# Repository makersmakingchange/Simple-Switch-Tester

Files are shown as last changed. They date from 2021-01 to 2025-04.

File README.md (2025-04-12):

# Simple Switch Tester
The Simple Switch Tester is a cost effective, open source assistive technology for testing assistive switches. When an assistive switch is connected to the tester via the 3.5 mm jack and activated, a light on the tester will illuminate indicating that the switch is functioning correctly. The tester is powered by two AAA batteries. A test button on the side of the tester allows the batteries to be tested to confirm the tester is working correctly before testing a switch.

The Simple Switch Tester is comprised of off-the-shelf electronics and 3D printed parts. The overall cost of materials is about $8 (plus $8 for component shipping).

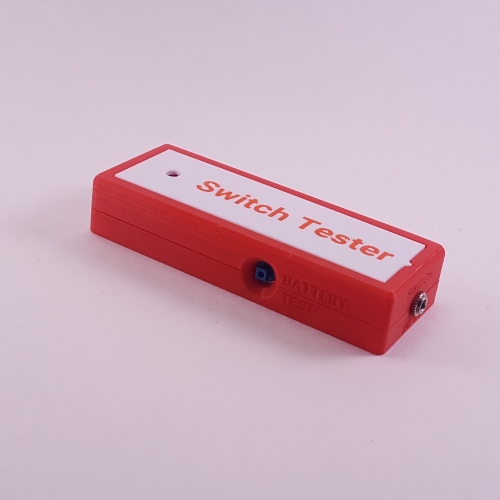
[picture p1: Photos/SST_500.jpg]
Simple Switch Tester


## More info at
 - [Makers Making Change Library Listing](https://www.makersmakingchange.com/s/product/simple-switch-tester/01tJR0000006948YAA) 

## Getting Started

### 1. Order the Off-The-Shelf Components

The [Bill of Materials](/Documentation/SST_BOM_v0.1.xlsx) lists all of the parts and components required to build the Simple Switch Tester. The electronic components may be available locally, but will probably need to be ordered online. For convenience, you can use this Digikey cart: https://www.digikey.ca/short/w37qmwmv

### 2. Print the 3D Printable components

Print the components for the switch tester case and choose an option for the case.

All of the files and individual print files can be in the [/Build_Files/3D_Printing_Files](/Build_Files/3D_Printing/) folder.

### 3. Assemble the Switch Tester

Reference the [assembly guide](/Documentation/SST_Assembly_Guide_v0.1.pdf) for the tools and steps required to build each portion. There is also a build video available at the following link: https://www.youtube.com/watch?v=CHm8Z5UD4Sw

## Files

### Documentation
| Document | Version | Link |
|---|---|---|
| Design Specifications| 0.1 | [SST_Design_Specifications](/Documentation/SST_Design_Rationale_v0.1.pdf) |
| Design Rationale | 0.1 | [SST_Design_Rationale](/Documentation/SST_Design_Rationale_v0.1.pdf) |
| Bill of Materials | 0.1 | [SST_BOM](/Documentation/SST_BOM_v0.1.xlsx) |
| Assembly Guide | 0.1 | [SST_Instructions](/Documentation/SST_Assembly_Guide_v0.1.pdf) |
| Maker Checklist | 0.1 | [SST_Checklist](/Documentation/SST_Maker_Checklist_v0.1.pdf) |
| Quick Guide | 0.1 | [SST_Quick_Guide](/Documentation/SST_Quick_Guide_v0.1.pdf) |
| Changelog | 0.1 | [SST_Changelog](/Documentation/SST_Changelog_v0.1.pdf) |

### Design Files
 - [CAD Files](/Design_Files)

### Build Files
 - [3D Printing Files](/Build_Files/3D_Printing)
 - [V0.1 3MF](/Build_Files/3D_Printing/SST_All_v0.1.3mf)

## License

Everything needed or used to design, make, test, or prepare the Simple Switch Tester is licensed under the CERN 2.0 Permissive license <https://ohwr.org/project/cernohl/wikis/Documents/CERN-OHL-version-2> (CERN-OHL-P) .

Accompanying material such as instruction manuals, videos, and other copyrightable works that are useful but not necessary to design, make, test, or prepare the Simple Switch Tester are published under a Creative Commons Attribution-ShareAlike 4.0 license <https://creativecommons.org/licenses/by-sa/4.0/> (CC BY-SA 4.0)

<!-- ABOUT MMC START -->
## About Makers Making Change
[Makers Making Change Logo](https://www.makersmakingchange.com/)

Makers Making Change is a program of [Neil Squire](https://www.neilsquire.ca/), a Canadian non-profit that uses technology, knowledge, and passion to empower people with disabilities.

Makers Making Change leverages the capacity of community based Makers, Disability Professionals and Volunteers to develop and deliver affordable Open Source Assistive Technologies.

 - Website: [www.MakersMakingChange.com](https://www.makersmakingchange.com/)
 - GitHub: [makersmakingchange](https://github.com/makersmakingchange)
 - Bluesky: [@makersmakingchange.bsky.social](https://bsky.app/profile/makersmakingchange.bsky.social)
 - Instagram: [@makersmakingchange](https://www.instagram.com/makersmakingchange)
 - Facebook: [makersmakechange](https://www.facebook.com/makersmakechange)
 - LinkedIn: [Neil Squire Society](https://www.linkedin.com/company/neil-squire-society/)
 - Thingiverse: [makersmakingchange](https://www.thingiverse.com/makersmakingchange/about)
 - Printables: [MakersMakingChange](https://www.printables.com/@MakersMakingChange)

### Contact Us
For technical questions, to get involved, or to share your experience we encourage you to [visit our website](https://www.makersmakingchange.com/) or [contact us](https://www.makersmakingchange.com/s/contact).
<!-- ABOUT MMC END -->

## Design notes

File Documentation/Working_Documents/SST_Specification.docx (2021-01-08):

# Introduction

The Simple Switch Tester is a device that provides a user with a way to assess the functionality of standard assistive switches that are equipped with a 3.5 mm plug.

# Specifications

1. Functionality
  1.1. The device must provide a 3.5 mm jack for connecting a switch.
  1.2. The device must provide feedback when a connected switch is activated.
  1.3. The device must have an enclosure to enclose and protect the electronic components.
  1.4. The device should provide a way to confirm that the tester is operational without requiring an external switch.
  1.5. The device should be able to be mounted.
2. Performance
  2.1. The device should operate
  2.2. The device should last in standby mode for no less than 6 months before requiring a battery change.
3. Environment
  3.1. The device must work in a typical indoor working environment.
4. Life expectancy
  4.1. The device should last the user up to ten years with constant use¹.
5. Maintenance
  5.1. The device battery must be easily accessible.
  5.2. The enclosure should be able to be cleaned.
  5.3. The enclosure should be able to be disinfected.
6. Target product cost
  6.1. The costs for a single device including materials and shipping must be less than $55 CAD.
  6.2. The costs for a single device including materials and shipping should be less than $20 CAD.
7. Availability of components
  7.1. The device must be comprised of components that are either commercially available off-the-shelf or that are 3D printable.
  7.2. Commercially available off-the-shelf components should available locally or online.
  7.3. 3D printable components should be printable on consumer-level fused filament fabrication (FFF) machines.
  7.4. Compatible alternative components should be listed.
8. Packaging
  8.1. The device must be easy to ship disassembled.
9. Transportation
  9.1. The device must be compact enough for ease of transportation of several devices.
  9.2. The device should be able to be transported in carry-on baggage (with lithium battery⁴.)
  9.3. The device should be able to ship in a letter-sized envelope (without battery³).
  9.4. The device should be able to ship in a half-letter sized envelope (without battery³).
10. Assembling/building
  10.1. The device should be manufacturable by a novice maker with limited tools in a remote location (e.g. at home).
  10.2. The device should be able to be assembled by a typical maker in less than an hour.
  10.3. The device should have guide pins, tracks, or other alignment markers to help guide the device assembly.
  10.4. The tools required to assemble the device should be limited to: a soldering iron, wire cutters, pliers, and/or a screwdriver.
11. Troubleshooting
  11.1. The primary user should be able to troubleshoot or reset critical product function(s) without requiring external help.
  11.2. Secondary users (caretaker, disability professional, family members, etc.) should be able to troubleshoot critical product function(s) and general functions without requiring external help.
  11.3. Troubleshooting support and documentation must be available online or in other forms for all stakeholders (primary user, secondary user, maker, etc.) and explained in non-technical terms.
12. Quantity
  12.1. The device must be able to be built in minimal quantities (i.e. 1-2).
  12.2. The device should be able to be built in larger quantities (i.e. 20-50).
13. Size and weight
  13.1. The device kit (including 3D printed casing) should not weigh more than 50g⁵.
  13.2. The device should be around the same size as a handheld device.
14. Aesthetics and finish
  14.1. The device should have a sleek look and not look bulky.
  14.2. The device should have Makers Making Change branding on the exterior.
15. Materials
  15.1. The 3D printed case must be printable in common filaments, like PLA and ABS, but not limited to other filaments.
16. Product life span
  16.1. The device should have a product lifespan of at least ten years¹.
17. Standards and specifications (provincial, national, international, etc.)
  17.1. The device must comply with Transport Canada regulation on shipping lithium metal batteries², ³.
18. Ergonomics
  18.1. The device must not have any sharp edges.
  18.2. The device should be comfortable to hold and use.
19. Quality and reliability
  19.1. The device must function reliably and consistently as a switch tester without failure.
20. Shelf life
  20.1. The device should have a shelf life of ten years¹.
21. Processes
  21.1. The enclosure design should be designed and optimized for 3D printing using a fused filament fabrication (FFF) machine.
  21.2. The enclosure design should use minimal or no support material to print.
  21.3. 3D printed components should require minimal post-processing.
22. Testing
  22.1. The device must be built and tested internally first before publication.
23. Safety
  23.1. The device must not injure the user in any way.
  23.2. The device must not pose a choking hazard.
24. Intellectual Property Protection
  24.1. The device must be released with an open-source license.
  24.2. All project deliverables should be licensed to comply with Open Source Hardware.
25. Product liability
  25.1. Any form of incorrect use of the device must not be the fault of Makers Making Change.
26. Installation and operation
  26.1. The device must have an easy to understand user manual.
  26.2. The device should have icons and arrows for instruction on the 3D printed case.
27. Disposal
  27.1. The device and its components must be able to be disposed of by regular household waste collection agencies or recycling depot, excluding the 3D printed enclosure.

# Appendix

¹ Shelf life of lithium coin battery

https://www.panasonic-batteries.com/en/specialty/lithium-coin/coin-lithium-cr2032

“Shelf Life: 10 years”

² Transport Canada on lithium batteries

https://tc.canada.ca/en/dangerous-goods/transportation-dangerous-goods/transporting-batteries

“The consignor is responsible for classifying dangerous goods (batteries in this case) in accordance with Part 2 of the TDG Regulations.”

“Yes. In Canada, the shipping and importing of lithium batteries is subject to the Transportation of Dangerous Goods Act, 1992 (TDG Act) and its regulations. They are considered dangerous goods much like gasoline, propane and sulfuric acid.”

Shipping documents are always required when transporting batteries.

Battery shipments must fully comply with the TDG Regulations

When shipping batteries by marine or air transport, consult Parts 11 and 12 of the TDG Regulations as well as the following documents:

The International Civil Aviation Organization’s Technical Instructions for the Safe Transport of Dangerous Goods by Air (ICAO Technical Instructions); or

The International Maritime Organization’s International Maritime Dangerous Goods Code (IMDG Code).

“A paper copy of the shipping document must always accompany the dangerous goods.”

“When dangerous goods are shipped by air, the shipping document must have, in the left and right margins, red hatchings that slant to the left or right.”

At minimum, the shipping document must include:

The name and address of the consignor in Canada

The shipping date

A description of the dangerous goods, in the following order:

The UN number

The shipping name of the dangerous goods

The primary and subsidiary class

Where applicable, the packing group in roman numerals

The quantity in metric (e.g., kg or L) for transports originating in Canada

Theʺ 24-Hour Numberʺ of a person who can provide technical information on the dangerous goods

The consignor’s certification

“Part 4 of the TDG Regulations requires that dangerous goods safety marks be displayed on the means of containment containing dangerous goods in transport.”

Packing Instruction 801 of Transport Canada Standard TP14850E

Batteries may be handled, offered for transport or transported in a non-UN standardized container if they are placed in a rigid container, in a wooden slatted crate or on a pallet

Batteries must be protected against short circuits

Stacked batteries must be adequately secured in tiers separated by a layer of non-conductive material

Battery terminals must not support the weight of other superimposed elements

Batteries must be packaged or secured to prevent inadvertent movement

³ UPS: How to safely pack and ship batteries

https://www.ups.com/ca/en/help-center/packaging-and-supplies/special-care-shipments/batteries.page

https://www.ups.com/assets/resources/media/en_CA/pack_ship_batteries.pdf

“Regulations require packing cells and batteries in fully enclosed inner packaging made of nonconductive material (e.g. plastic bags) and ensuring that exposed terminals or connectors are protected with non-conductive caps or tape or by other similar means.”

“Do not use envelopes or other softsided packs.”

Air Shipments of Lithium Metal Batteries of <2g of Lithium metal (Figure 9)

https://data.energizer.com/pdfs/cr2032.pdf

“Typical Weight: 3.0 grams (0.10 oz.)”

“Typical Li Content: 0.109 grams (0.0038 oz.)”

“Your package does not need to be shipped as fully regulated Dangerous Goods. Please see IATA regulations for UN3091 Section II requirements. http://www.iata.org/ All packages of 'Lithium metal batteries packed with equipment'* require the UN3091 Lithium battery mark. Also mark the package 'P.I. 969-II'.† For 'Lithium metal batteries contained in equipment', display the UN3091 Lithium battery mark for any single package that contains >4 cells or >2 batteries. Also, mark the package 'P.I. 970-II'. † Note: If there are no more than 4 cells or 2 batteries and no more than 2 packages in a consignment, no markings or labels are required.”

⁴ Canada Post shipping

https://www.canadapost.ca/cpotools/apps/far/business/farLetter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

| Canada | U.S. | International
0—30g | $1.07 / stamp $0.92 / stamp in a booklet | $1.30 | $2.71
Over 30g—50g | $1.30 | $1.94 | $3.88

TSA lithium battery carry-on rules

https://www.tsa.gov/travel/security-screening/whatcanibring/items/lithium-batteries-more-100-watt-hours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,the%20FAA%20regulations%20on%20batteries.

“Lithium batteries with more than 100 watt hours may be allowed in carry-on bags with airline approval. One spare battery, not exceeding 300 watt hours, or two spare batteries, not exceeding 160 watt hours each, are permitted in carry-on bags.”

https://www.master-instruments.com.au/products/54908/CR2032/BN.html

“0.66Wh”

© 2020 by Neil Squire. “Simple Switch Tester Specification” is licensed under the CC BY SA 4.0 License: http://creativecommons.org/licenses/by-sa/4.0 PAGE 1 OF 3 Design files available at https://www.makersmakingchange.com/project/simple-switch-tester/

V0.1 | DECEMBER 2020 Simple Switch Tester Specifications

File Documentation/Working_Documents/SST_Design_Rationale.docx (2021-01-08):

# Introduction

The Simple Switch Tester is a device used to test the functionality of an assistive switch with a 3.5 mm connection. that allowsenables a user to test the switch they have built, in order to determine if they assembled it successfully and that all the components are working. When a switch is plugged into the 3.5 mm jack and activated, an LED will light up indicating a successfully operating switch. The device can be used at build events to test a series of switches, or at home during a digital build event. The switch tester is a simple device made up of six main components: the 3.5 mm jack, a AAA battery holder, two AAA batteries, an LED, a 68 Ω resistor, and a tactile switch working in parallel that can test the batteries as well as the switch. The total cost of the device is well below other equivalent devices on the market by sourcing inexpensive components and utilizing FDM 3D printing.

Table 1: Commercially Available Options

Name | Vendor | Cost | Link
Single Switch Tester | AbleNet | $55 USD Switch Tester | https://www.ablenetinc.com/technology/single-switch-tester

Switch Selection

Currently, only one design, created by AbleNet, is available commercially as a Switch Tester.

# Ideation

## Feedback

The core purpose of the test is to provide some sort of feedback to the user if a connected with

The Simple Switch Tester incorporates an enclosure and more cost-effective components than the previous version. Below is a picture of some concepts that were explored in the ideation process. Between different enclosure shapes, components, and snap-fit and solderless methods, the newest version was created. Different circuits were considered (below sketches) when thinking of the functionality of the design, ultimately opting for a parallel circuit battery tester, as well as an external switch tester to ensure that there is no miscommunication between a dead battery versus an incorrectly assembled switch. A lithophane was chosen as the top of the enclosure because the LED can shine through, displaying whatever image and/or text is on it. In case the user can only use black or very dark filament for the lithophane, there is a version of the model with a hold for the LED to shine through. The idea of disassembling locally sourced devices and utilizing their components was explored but later decided against for reasons of consistency and availability of the components. It was discovered that the 6” wires that come with the battery holder can serve as wire for the entire circuit, eliminating the need for external wire.

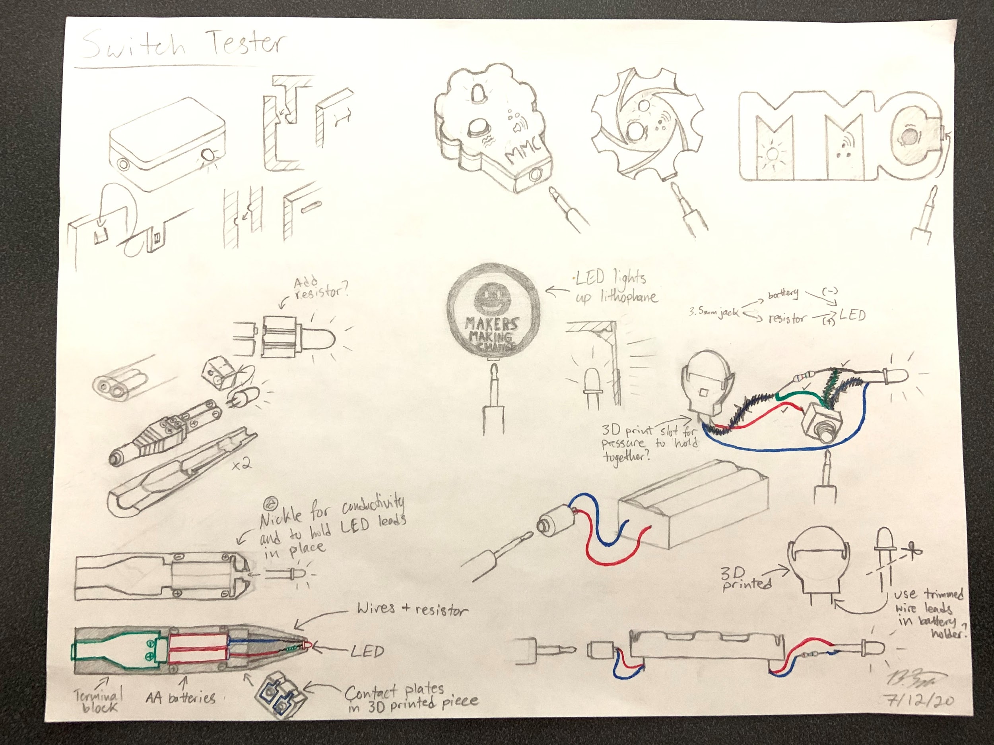
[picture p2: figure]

## Circuit Options

Persistent Power Light and Master On/Off Switch Momentary battery tester

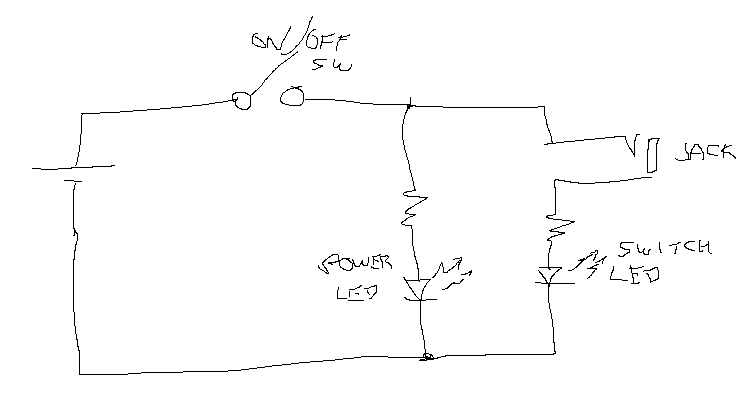
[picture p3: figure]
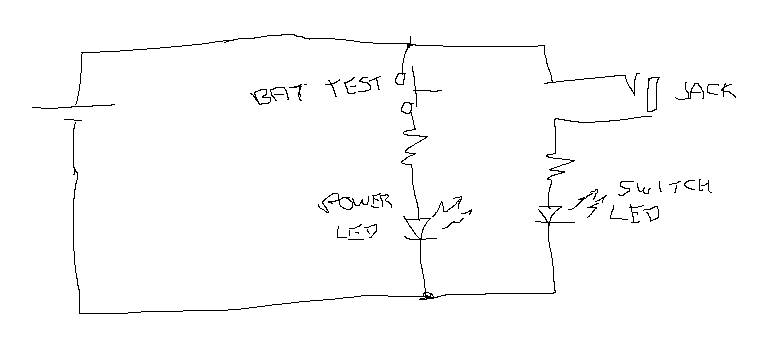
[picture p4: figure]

Simplest Version - No battery tester Simple Version with test button

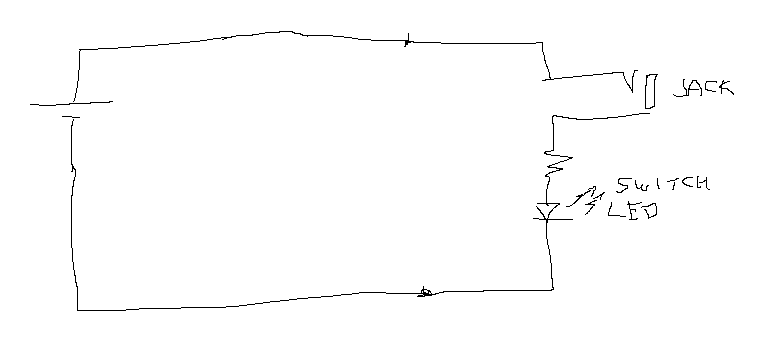
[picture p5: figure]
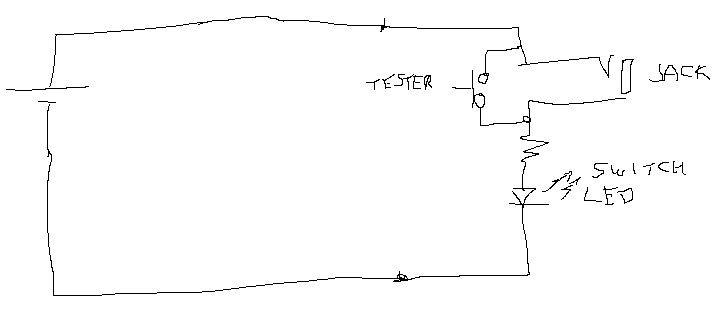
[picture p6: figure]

## Power Source

The Switch Tester requires a power source to test the switch and provide feedback to the user. Since the design is meant to be portable, it was necessary for the tester to have a portable power source as well. This rules out using a plug / line voltage and directed to some type of battery.

A number of battery options were considered. The primary options were either two AA/AAA cells or a 3V lithium coin cell.

# Version 1.0

The final design is comprised of a simple battery operated circuit that is soldered together and then inserted into a 3D printed enclosure. The 3D printed enclosure consists of a base, a top with a cover.

## Circuit

For this version, a circuit with a parallel test button and light feedback was selected. The components for the device can be found at online retailers such as Digi-key.

## Enclosure

The enclosure is comprised of a two-part case that connects together with a snap-fit.

### Snap-Fit

### Labelling

The top edges of the enclosure have a fillet/round, while the bottom edges of the enclosure have a small chamfer. This is a feature to help indicate how the enclosure is expected to sit on the table. The small chamfer on the bottom edge improves 3D printability.

## Components

The battery will be easily accessible if it needs to be changed.

The 3D printed enclosure can be printed in any material, but PLA is preferred for cost, availability, and ease-of-printing. PETg is a good alternative option.

## Assembly

The device requires the following tools and equipment for assembly: a soldering iron, pliers, wire strippers, flush cutters, and a 3D printer (or temporary access to one). After the enclosure is 3D printed, the device can be assembled in a few short steps. The 3D printed enclosure is snap-fit and requires no additional parts to assemble it. The total build time should be under thirty minutes after the enclosure is finished printing.

Wiring

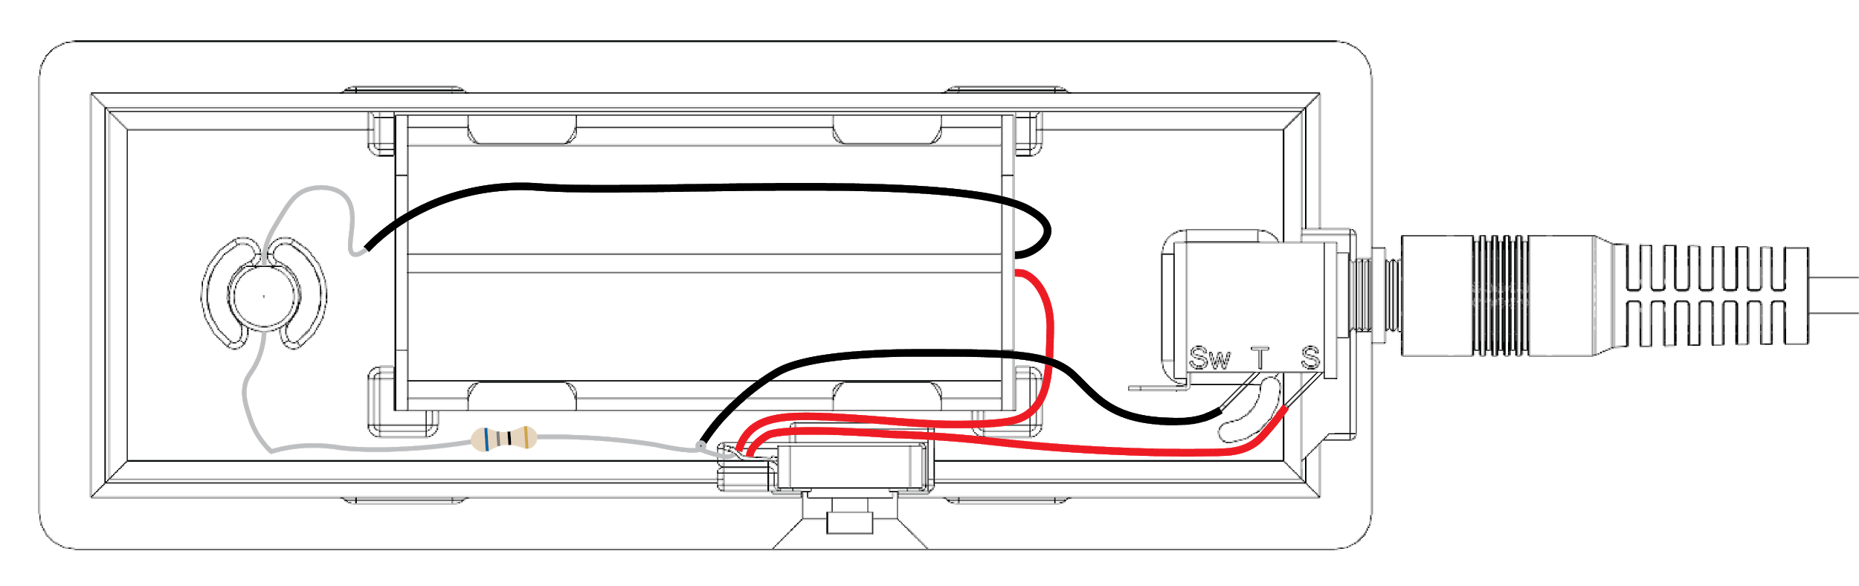
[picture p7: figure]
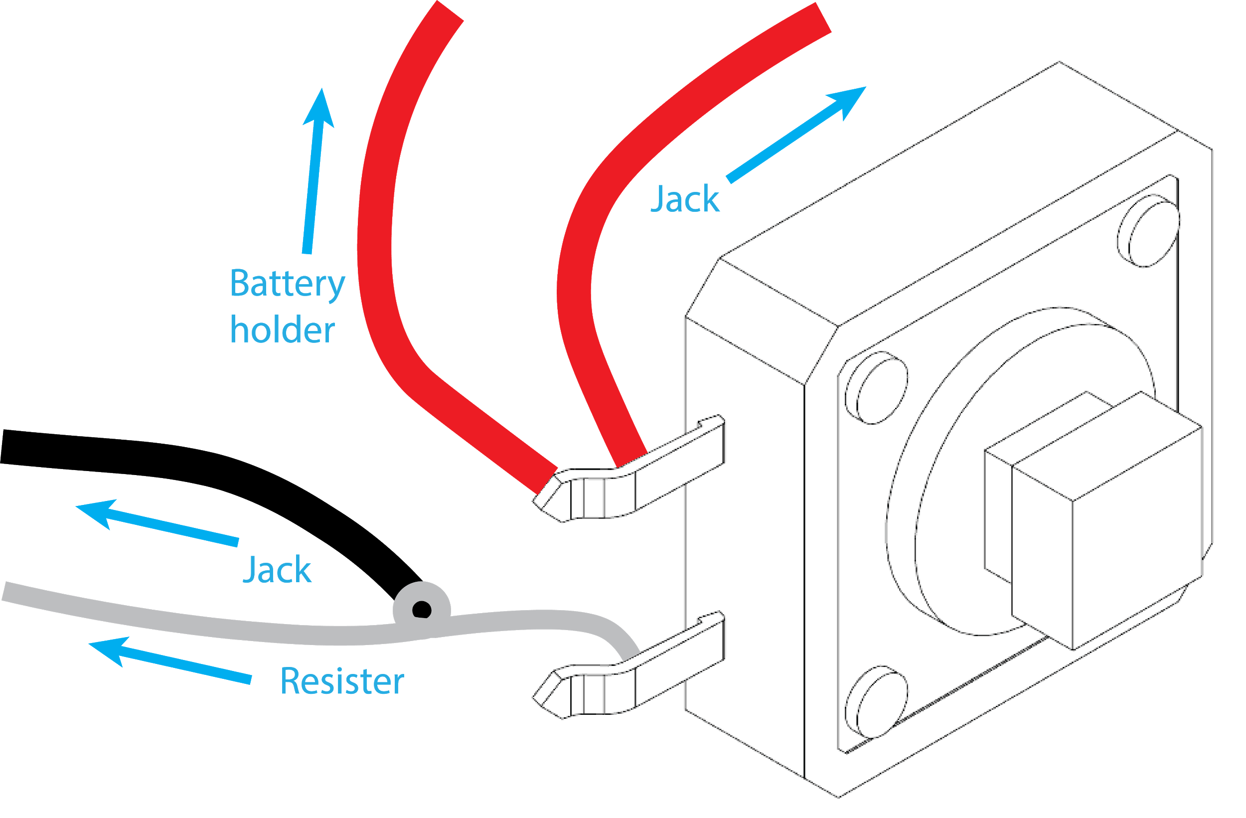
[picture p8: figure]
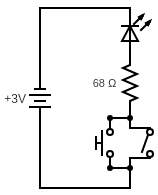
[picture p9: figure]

# Possible Future Developments

Feedback

A future version of the switch tester could include haptic as well as auditory feedback on top of the visual LED feedback it already provides. Of these, auditory feedback is probably the most desirable and easiest to implement.

Case Design

The enclosure could be modified slightly to fit new or existing components better (i.e. sinking the area where the nut screws on to the jack).

The option to use different lithophanes; such as seasonal, event-specific, personalized, etc. could also be explored.

Easier Enclosure Opening

Depending on the tolerance of the printing, the snap fit may be quite tight, making it difficult to open the case to swap the batteries. A feature could be added to help make it easier to open the case. For example, a slot that could be used with a screwdriver / butter knife / coin to help pry open the case.

Lithophane

The enclosure could be modified to capture the Lithophane from the bottom and avoid the use of super glue to attach it to the top. This would make it easier to temporarily swap out the cover for special events as well.

© 2020 by Neil Squire. “SST Design Rationale” is licensed under the CC BY SA 4.0 License: http://creativecommons.org/licenses/by-sa/4.0 Design files available at https://www.makersmakingchange.com/project/simple-switch-tester

V0.1 | December 2020 Simple Switch Tester DESIGN RATIONALE

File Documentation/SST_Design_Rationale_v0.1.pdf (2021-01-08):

V0.1 | December 2020

# Simple Switch Tester

DESIGN RATIONALE

© 2020 by Neil Squire. (https://neilsquire.ca/) “SST Design Rationale” is licensed under the CC BY SA 4.0 License: http://creativecommons.org/licenses/by-sa/4.0 Design files available at https://www.makersmakingchange.com/project/simple-switch-tester

# Introduction

The Simple Switch Tester is a device used to test the functionality of an assistive switch with a 3.5 mm connection. that allowsenables a user to test the switch they have built, in order to determine if they assembled it successfully and that all the components are working. When a switch is plugged into the 3.5 mm jack and activated, an LED will light up indicating a successfully operating switch. The device can be used at build events to test a series of switches, or at home during a digital build event. The switch tester is a simple device made up of six main components: the 3.5 mm jack, a AAA battery holder, two AAA batteries, an LED, a 68 Ω resistor, and a tactile switch working in parallel that can test the batteries as well as the switch. The total cost of the device is well below other equivalent devices on the market by sourcing inexpensive components and utilizing FDM 3D printing.

Table 1: Commercially Available Options

Name | Vendor | Cost | Link
Single Switch Tester | AbleNet | $55 USD Switch Tester | https://www.ablenetinc.com/technology/single-switch-tester

### Switch Selection

Currently, only one design, created by AbleNet, is available commercially as a Switch Tester.

# Ideation

## Feedback

The core purpose of the test is to provide some sort of feedback to the user if a connected with

DESIGN RATIONALE
The Simple Switch Tester incorporates an enclosure and more cost-effective components than the previous version. Below is a picture of some concepts that were explored in the ideation process. Between different enclosure shapes, components, and snap-fit and solderless methods, the newest version was created. Different circuits were considered (below sketches) when thinking of the functionality of the design, ultimately opting for a parallel circuit battery tester, as well as an external switch tester to ensure that there is no miscommunication between a dead battery versus an incorrectly assembled switch. A lithophane was chosen as the top of the enclosure because the LED can shine through, displaying whatever image and/or text is on it. In case the user can only use black or very dark filament for the lithophane, there is a version of the model with a hold for the LED to shine through. The idea of disassembling locally sourced devices and utilizing their components was explored but later decided against for reasons of consistency and availability of the components. It was discovered that the 6” wires that come with the battery holder can serve as wire for the entire circuit, eliminating the need for external wire.

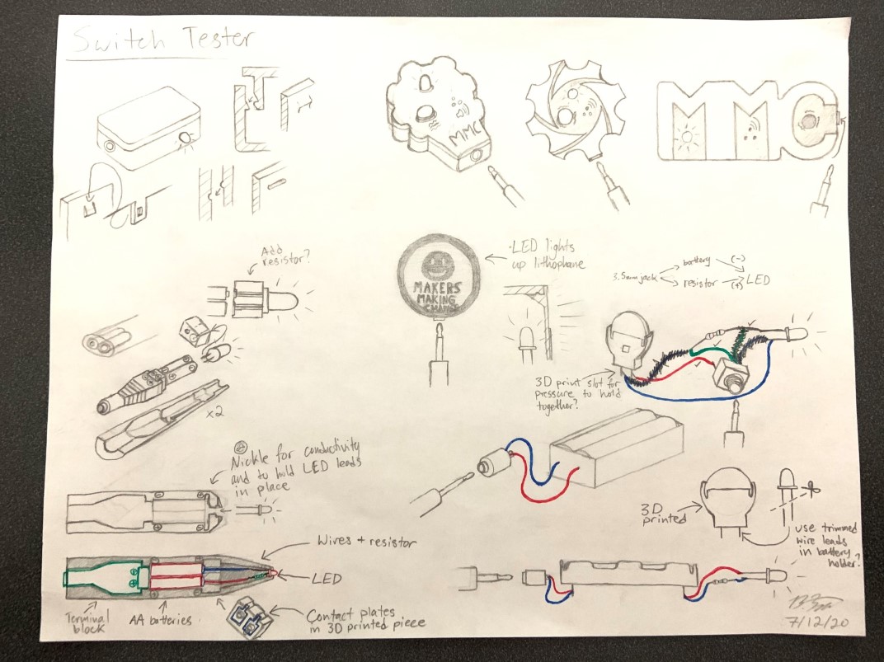
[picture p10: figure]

## Circuit Options

Persistent Power Light and Master On/Off Switch | Momentary battery tester

DESIGN RATIONALE

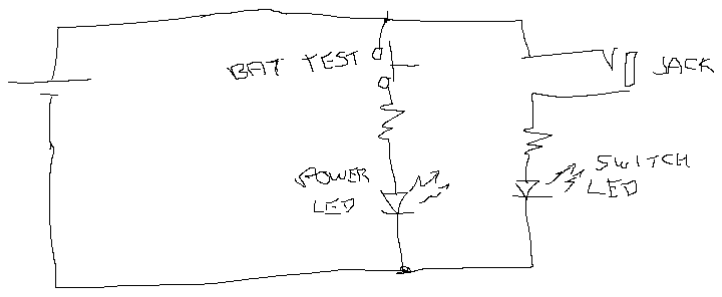
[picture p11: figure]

Simplest Version - No battery tester | Simple Version with test button

## Power Source

The Switch Tester requires a power source to test the switch and provide feedback to the user. Since the design is meant to be portable, it was necessary for the tester to have a portable power source as well. This rules out using a plug / line voltage and directed to some type of battery.

A number of battery options were considered. The primary options were either two AA/AAA cells or a 3V lithium coin cell.

# Version 1.0

The final design is comprised of a simple battery operated circuit that is soldered together and then inserted into a 3D printed enclosure. The 3D printed enclosure consists of a base, a top with a cover.

DESIGN RATIONALE

## Circuit

For this version, a circuit with a parallel test button and light feedback was selected. The components for the device can be found at online retailers such as Digi-key.

## Enclosure

The enclosure is comprised of a two-part case that connects together with a snap-fit.

### Snap-Fit

### Labelling

The top edges of the enclosure have a fillet/round, while the bottom edges of the enclosure have a small chamfer. This is a feature to help indicate how the enclosure is expected to sit on the table. The small chamfer on the bottom edge improves 3D printability.

## Components

The battery will be easily accessible if it needs to be changed.

The 3D printed enclosure can be printed in any material, but PLA is preferred for cost, availability, and ease-of-printing. PETg is a good alternative option.

## Assembly

The device requires the following tools and equipment for assembly: a soldering iron, pliers, wire strippers, flush cutters, and a 3D printer (or temporary access to one). After the enclosure is 3D printed, the device can be assembled in a few short steps. The 3D printed enclosure is snap-fit and requires no additional parts to assemble it. The total build time should be under thirty minutes after the enclosure is finished printing.

DESIGN RATIONALE

### Wiring

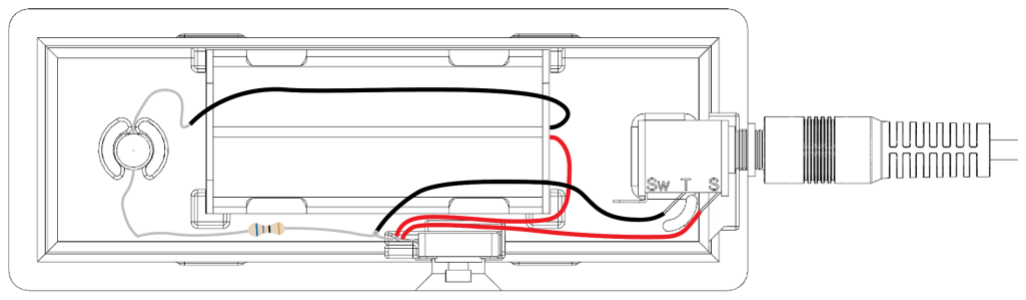
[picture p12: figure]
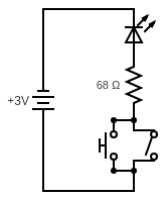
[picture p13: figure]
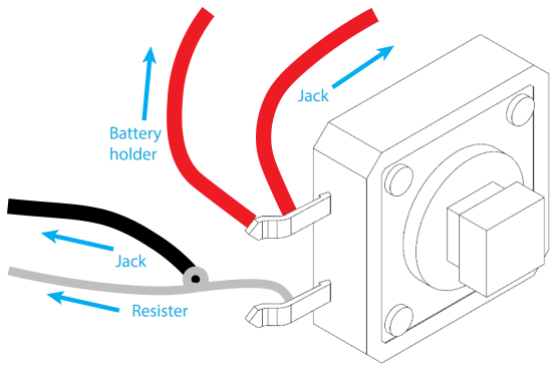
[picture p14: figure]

DESIGN RATIONALE

# Possible Future Developments

Feedback

A future version of the switch tester could include haptic as well as auditory feedback on top of the visual LED feedback it already provides. Of these, auditory feedback is probably the most desirable and easiest to implement.

Case Design

The enclosure could be modified slightly to fit new or existing components better (i.e. sinking the area where the nut screws on to the jack).

The option to use different lithophanes; such as seasonal, event-specific, personalized, etc. could also be explored.

Easier Enclosure Opening

Depending on the tolerance of the printing, the snap fit may be quite tight, making it difficult to open the case to swap the batteries. A feature could be added to help make it easier to open the case. For example, a slot that could be used with a screwdriver / butter knife / coin to help pry open the case.

Lithophane

The enclosure could be modified to capture the Lithophane from the bottom and avoid the use of super glue to attach it to the top. This would make it easier to temporarily swap out the cover for special events as well.

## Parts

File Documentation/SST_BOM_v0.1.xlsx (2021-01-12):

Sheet: Individual Maker Purchase
Component | Component name | Qty Req'd | Order size | Qty / Pkg | $/ Pkg | Extended | Tax (5% + 7%) | Shipping | Duties | $/ piece w/ all fees | Total | Purchase Source | Manufacturer | COO | MPN | Purchase Source SKU |  | URL (CAD) | URL (US) | URL (other)
 |  |  |  |  |  |  | 0.13 |  |  |  | $15.99
SST | BC2AAAW Battery Holder | 1 | 1 | 1 | $1.93 | $1.93 | $0.25 | $1.33 | $0.00 | $3.51 | $3.51 | Digikey |  |  | BC2AAAW | BC2AAAW-ND |  | https://www.digikey.ca/short/zrbrth | https://www.digikey.com/product-detail/en/mpd-memory-protection-devices/BC2AAAW/BC2AAAW-ND/66741
 | Tactile Switch B3F-5050 | 1 | 1 | 1 | $0.77 | $0.77 | $0.10 | $1.33 | $0.00 | $2.20 | $2.20 | Digikey |  |  | B3F-5050 | SW801-ND |  | https://www.digikey.ca/short/zrbrt0 | https://www.digikey.com/product-detail/en/omron-electronics-inc-emc-div/B3F-5050/SW801-ND/368377
 | 35RAPC2AV 3.5 mm jack | 1 | 1 | 1 | $1.83 | $1.83 | $0.24 | $1.33 | $0.00 | $3.40 | $3.40 | Digikey |  |  | 35RAPC2AV | SC1457-ND |  | https://www.digikey.ca/short/zrbr3t | https://www.digikey.com/product-detail/en/switchcraft-inc/35RAPC2AV/SC1457-ND/772080
 | LED (Red or Other) | 1 | 1 | 1 | $0.48 | $0.48 | $0.06 | $1.33 | $0.00 | $1.88 | $1.88 | Digikey |  |  | LTL2R3KRD-EM | 160-1853-ND |  | https://www.digikey.ca/short/zrbr3j | https://www.digikey.com/product-detail/en/lite-on-inc/LTL2R3KRD-EM/160-1853-ND/2675133
 | 68 Ohm 1/4 Watt Resistor | 1 | 1 | 1 | $0.15 | $0.15 | $0.02 | $1.33 | $0.00 | $1.50 | $1.50 | Digikey |  |  | CF14JT68R0 | CF14JT68R0CT-ND |  | https://www.digikey.ca/short/zrbr34 | https://www.digikey.com/product-detail/en/stackpole-electronics-inc/CF14JT68R0/CF14JT68R0CT-ND/1830323
 | AAA Batteries | 2 | 2 | 2 | $0.56 | $1.12 | $0.15 | $1.33 | $0.00 | $2.60 | $2.40 | Digikey |  |  | LR03XWA/B | P645-ND |  | https://www.digikey.ca/short/z1vv0q | https://www.digikey.com/short/z1vv0m
 |  |  |  |  |  |  |  |  |  |  |  |  |  |  |  |  | Digikey Cart: | https://www.digikey.ca/short/47cdmb
(~$25.40/kg) | 3D Printed Cover plate (6.09 g) (26m) | 1 | 1 | 1 | $0.15 | $0.15 | $0.00 | $0.00 | $0.00 | $0.15 | $0.15
 | 3D Printed Enclosure Top (15.06 g) (1h13m) | 1 | 1 | 1 | $0.38 | $0.38 | $0.00 | $0.00 | $0.00 | $0.38 | $0.38
 | 3D Printed Enclosure Bottom (22.43 g) (1h33m) | 1 | 1 | 1 | $0.57 | $0.57 | $0.00 | $0.00 | $0.00 | $0.57 | $0.57
(optional) | 3D Printed Cover plate (hole) (6.05 g) (26m) | 0 | 1 | 1 | $0.15 | $0.15 | $0.00 | $0.00 | $0.00 | $0.15 | $0.15
3D Prints together | 43.47g, 3h12m, $1.10
3D Prints together (hole) | 43.43g, 3h12m, $1.10

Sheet: Bulk Purchase
Component | Component name | Qty needed | Order size | #/ pack or min quantity | $/ pack | tax | shipping | duties | $/ piece w/ all fees | $/ component w/ all fees | Purchase Source | Manufacturer | MPN | Purchase Source SKU | URL (CAD) | URL (US) | URL (other)
 |  |  |  |  |  |  |  |  |  | $6.00
SST | BC2AAAW Battery Holder | 1 | 50 | 1 | $71.49 | $3.57 | - | - | $1.50 | $1.50 | Digikey | MPD (Memory Protection Devices) | BC2AAAW | BC2AAAW-ND | https://www.digikey.ca/short/zrbrth | https://www.digikey.com/product-detail/en/mpd-memory-protection-devices/BC2AAAW/BC2AAAW-ND/66741
 | Tactile Switch B3F-5050 | 1 | 50 | 1 | $35.82 | $1.79 | - | - | $0.75 | $0.75 | Digikey | Omron Electronics Inc-EMC Div | B3F-5050 | SW801-ND | https://www.digikey.ca/short/zrbrt0 | https://www.digikey.com/product-detail/en/omron-electronics-inc-emc-div/B3F-5050/SW801-ND/368377
 | 35RAPC2AV 3.5mm jack | 1 | 50 | 1 | $74.89 | $3.74 | - | - | $1.57 | $1.57 | Digikey | Switchcraft Inc. | 35RAPC2AV | SC1457-ND | https://www.digikey.ca/short/zrbr3t | https://www.digikey.com/product-detail/en/switchcraft-inc/35RAPC2AV/SC1457-ND/772080
 | LED (Red or Other) | 1 | 50 | 1 | $17.30 | $0.87 | - | - | $0.36 | $0.36 | Digikey | Lite-On Inc. | LTL2R3KRD-EM | 160-1853-ND | https://www.digikey.ca/short/zrbr3j | https://www.digikey.com/product-detail/en/lite-on-inc/LTL2R3KRD-EM/160-1853-ND/2675133
 | CF14JT68R0 Resistor | 1 | 50 | 1 | $1.63 | $0.08 | - | - | $0.03 | $0.03 | Digikey | Stackpole Electronics Inc | CF14JT68R0 | CF14JT68R0CT-ND | https://www.digikey.ca/short/zrbr34 | https://www.digikey.com/product-detail/en/stackpole-electronics-inc/CF14JT68R0/CF14JT68R0CT-ND/1830323
 | AAA Batteries | 2 | 100 | 1 | $32.26 | $1.61 | - | - | $0.34 | $0.68 | Digikey | FDK America, Inc., a member of Fujitsu Group | LR03 C (2S) | SY627-ND | https://www.digikey.ca/short/zrbrzz | https://www.digikey.com/product-detail/en/fdk-america-inc-a-member-of-fujitsu-group/LR03-C-2S/SY627-ND/5305213
 | 3D Printed Cover plate (6.09 g) (26m) | 1 | 50 | 1 | $7.50 | $0.00 | - | - | $0.15 | $0.15 | PrusaSlicer
 | 3D Printed Enclosure Top (15.06 g) (1h13m) | 1 | 50 | 1 | $19.00 | $0.00 | - | - | $0.38 | $0.38 | PrusaSlicer
 | 3D Printed Enclosure Bottom (22.43 g) (1h33m) | 1 | 50 | 1 | $28.50 | $0.00 | - | - | $0.57 | $0.57 | PrusaSlicer
(optional) | 3D Printed Cover plate (hole) (6.05 g) (26m) | 1 | 50 | 1 | $7.50 | $0.00 | - | - | $0.15 | $0.15 | PrusaSlicer
 |  |  |  |  |  |  |  |  | Before tax | $216.09
 |  |  |  |  |  |  |  |  | Tax | $10.80
 |  |  |  |  |  |  |  |  | Total (Digikey) | $226.89
 |  |  |  |  |  |  |  |  | 3D prints | $55.00
 |  |  |  |  |  |  |  |  | Total | $508.78

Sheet: Comparison
 |  |  | Digikey
Component | Component name | Qty needed | Maker | Bulk | Difference
 |  |  | $16.14 | $6.14 | $10.00
Required | BC2AAAW Battery Holder | 1 | $3.51 | $1.50 | -$2.01
Required | Tactile Switch B3F-5050 | 1 | $2.20 | $0.75 | -$1.45
Required | 35RAPC2AV 3.5mm jack | 1 | $3.40 | $1.57 | -$1.83
Required | LED (Red or Other) | 1 | $1.88 | $0.36 | -$1.52
Required | CF14JT68R0 Resistor | 1 | $1.50 | $0.03 | -$1.47
Required | AAA Batteries | 2 | $2.40 | $0.68 | -$1.72
Required | 3D Printed Cover plate (6.09 g) (26m) | 1 | $0.15 | $0.15 | $0.00
Required | 3D Printed Enclosure Top (15.06 g) (1h13m) | 1 | $0.38 | $0.38 | $0.00
Required | 3D Printed Enclosure Bottom (22.43 g) (1h33m) | 1 | $0.57 | $0.57 | $0.00
(optional) | 3D Printed Cover plate (hole) (6.05 g) (26m) | 1 | $0.15 | $0.15 | $0.00

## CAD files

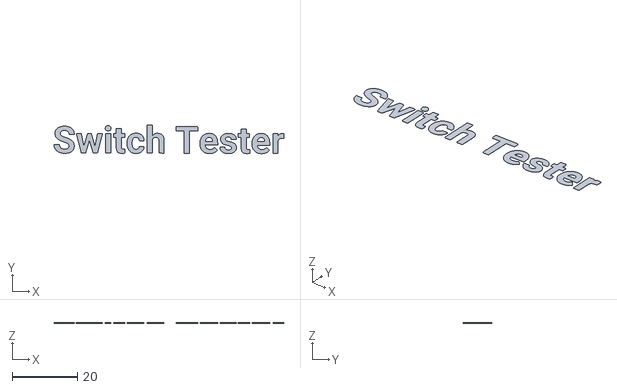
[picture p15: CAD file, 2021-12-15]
Build_Files/3D_Printing/Dual_Color_Cover_Plate/SST_Dual_Letters.stl
70.5 x 8.77 x 0.2

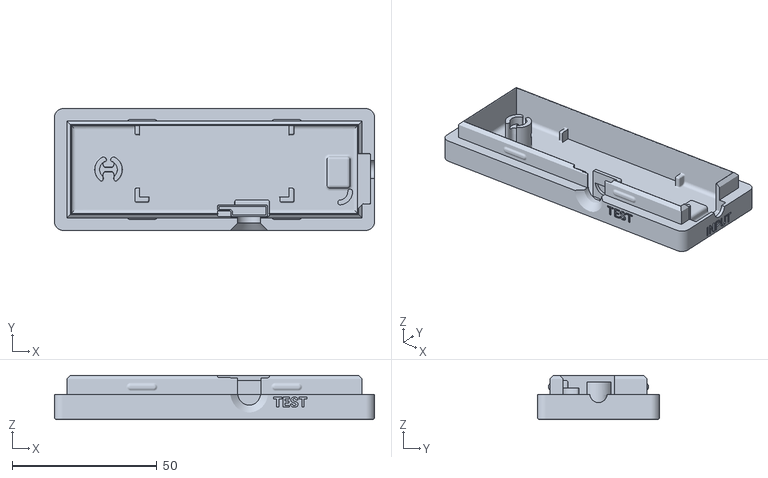
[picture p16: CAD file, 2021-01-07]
Build_Files/3D_Printing/SST_Enclosure_Bottom.stl
110.6 x 42.1 x 15.3

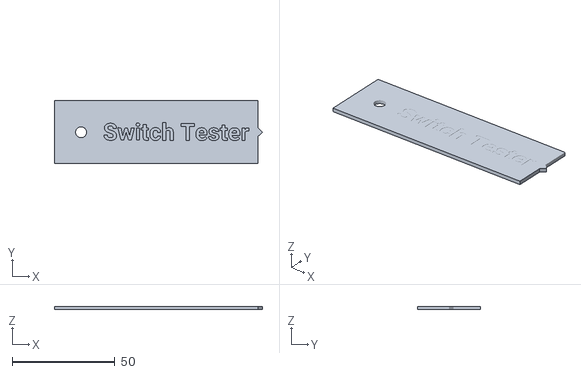
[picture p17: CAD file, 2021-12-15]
Build_Files/3D_Printing/Dual_Color_Cover_Plate/SST_Dual_Cover_Plate.stl
101.1 x 30.5 x 1.67

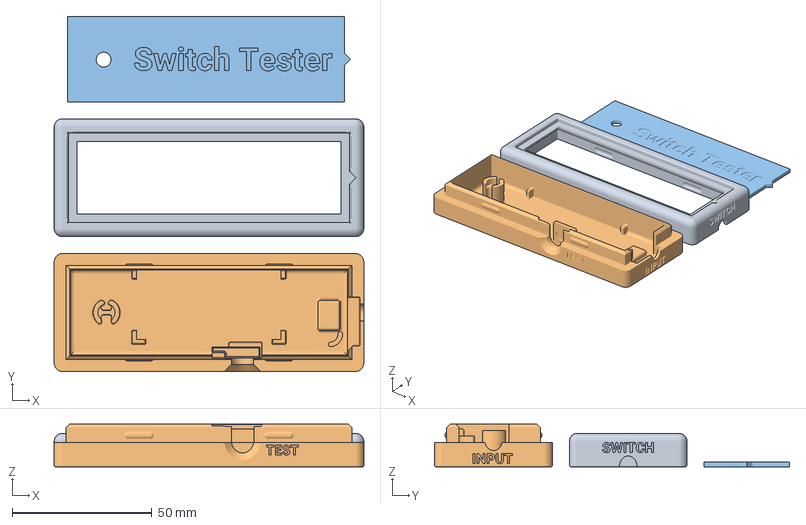
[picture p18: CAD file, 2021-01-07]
Build_Files/3D_Printing/SST_All_X1_0.2mm_PLA_MK3S_3h12m.3mf
110.6 x 126.8 x 15.3 mm
SST_Enclosure_Top.stl
SST_Enclosure_Bottom.stl
SST_Cover_Plate_Plain.stl

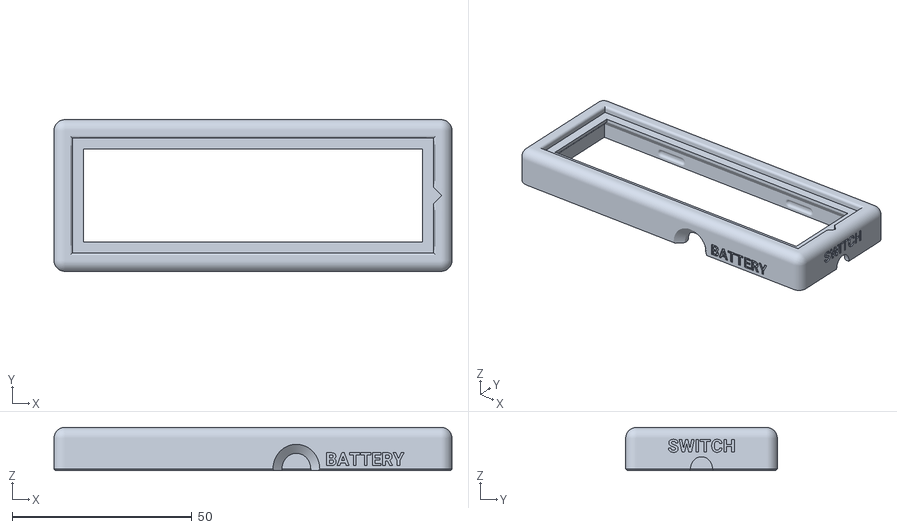
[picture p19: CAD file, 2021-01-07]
Build_Files/3D_Printing/SST_Enclosure_Top.stl
110.6 x 42.1 x 12.0

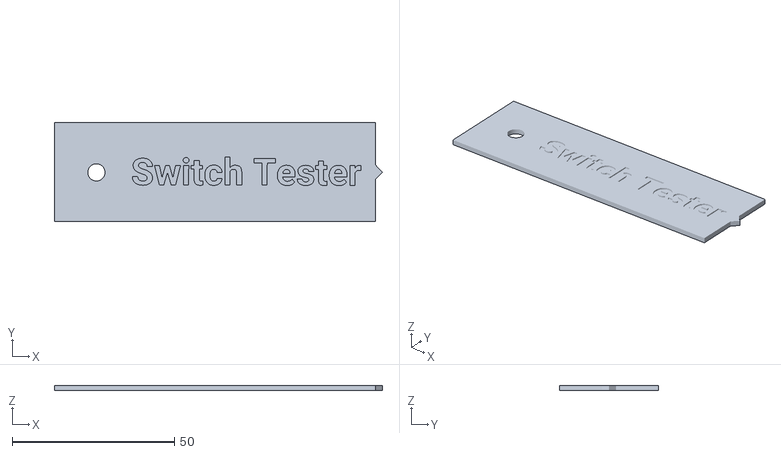
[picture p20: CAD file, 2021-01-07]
Build_Files/3D_Printing/SST_Cover_Plate_Plain.stl
101.1 x 30.5 x 1.67

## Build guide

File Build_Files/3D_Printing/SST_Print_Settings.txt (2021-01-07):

Print all components in orientation of STL file.

----------------------------
First print:
SST_Cover_Plate_Plain
SST_Enclosure_Top
SST_Enclosure_Bottom

Infill: 20%
Layer Height: 0.2mm
Support Material: No
Raft: No
----------------------------

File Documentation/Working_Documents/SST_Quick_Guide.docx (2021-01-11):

Introduction

The Simple Switch Tester enables a user to test the functionality of an assistive switch equipped with a 3.5 mm plug. When a switch is plugged into the 3.5 mm jack and activated, an indicator light will illuminate indicating a successfully operating switch.

Features

Indicator Light

Battery Test Button

3.5 mm Switch Input Jack

Specification

Size | 110 x 42 x 21 mm (w x d x h)
Input | 3.5 mm
Batteries | 2 X AAA
Disinfection | Ethyl Alcohol, Isopropyl Alcohol, Hydrogen Peroxide

Usage – Check Tester

1. Press the “BATTERY TEST” button on the side of the enclosure.
2. If the batteries are working, the indicator light will turn on.

Usage – Test Switch

1. Plug an assistive switch into the 3.5 mm input jack on the end of the enclosure.
2. The indicator light should NOT turn on. If it does, there may be something wrong with the switch.
3. Activate the assistive switch.
4. The indicator light should turn ON. If the light does not turn on, there may be something wrong with the switch.

Cleaning

Wipe the exterior of the enclosure with a damp cloth.

Troubleshooting

Issue: Indicator light does not turn on when the “BATTERY TEST” button is pushed:

1. Check that the batteries are fresh and installed in the correct direction (indicated on the battery holder).

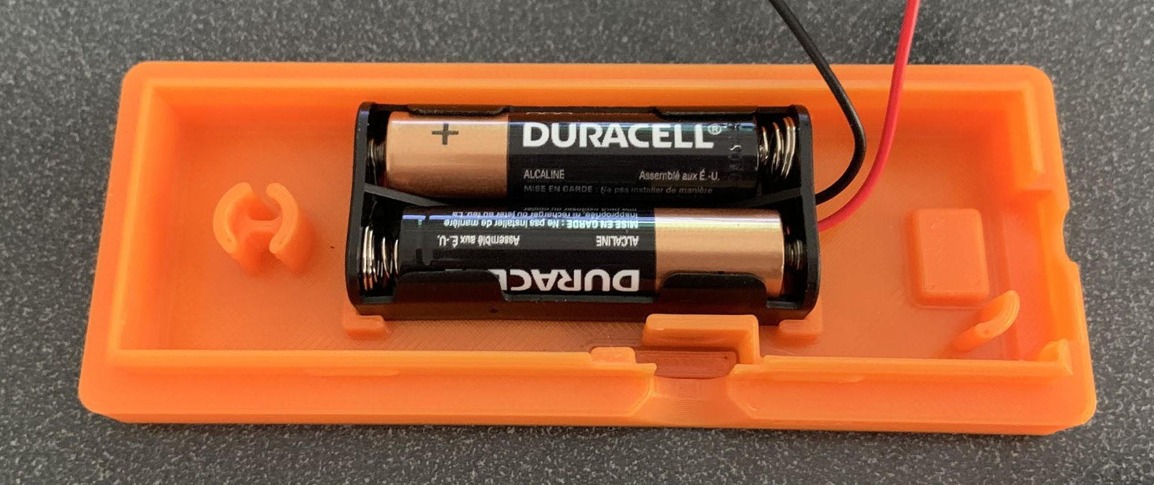
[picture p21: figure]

2. Check to make sure all the wires are connected correctly and in the right spots.

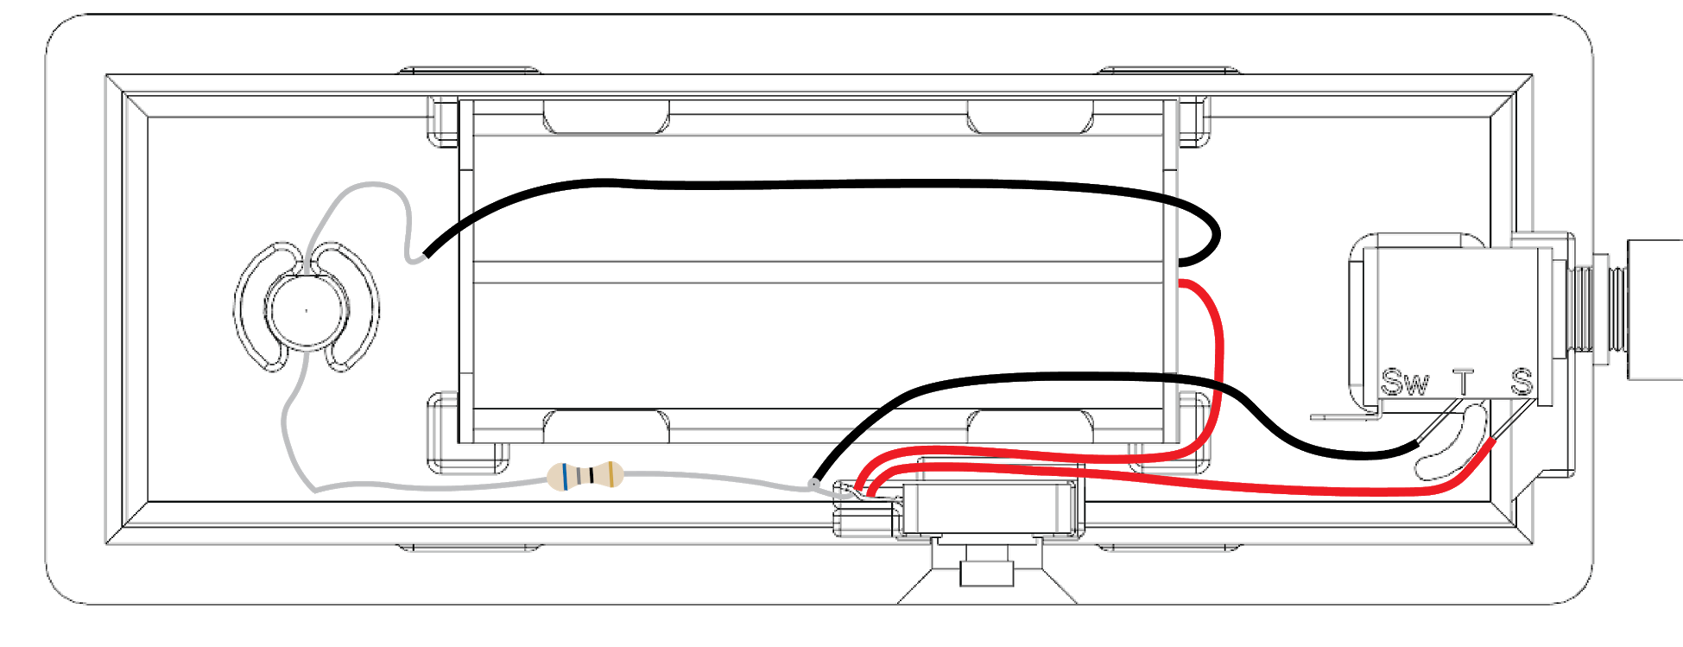
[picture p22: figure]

The LED stays on all the time:

1. Make sure the wires are not accidentally touching each other or soldered together incorrectly.

The LED turns on when the test button is pushed, but not when the assistive switch is activated:

1. Check to ensure the assistive switch is plugged into the jack correctly/all the way.
2. The assistive switch may not be assembled correctly/not working.

Replacing Batteries

Replacing the Batteries

1. Loosen the 3.5 mm jack nut without removing it and pull apart the two halves of the enclosure, exposing the electronics inside.
2. Remove the old batteries and dispose of them appropriately (recycle or recharge).
3. Insert the two new AAA batteries. Ensure they are installed in the correct orientation.
4. Check the tester by pressing the “BATTERY TEST” button to see if the indicator light illuminates.
5. Re-assemble the enclosure. Snap the two halves back together and tighten the nut on the 3.5 mm jack.

© 2020 by Neil Squire. This work is licensed under the CC BY SA 4.0 License: http://creativecommons.org/licenses/by-sa/4.0 Design files available at https://www.makersmakingchange.com/project/simple-switch-tester

V0.1 | DECEMBER 2020 Simple Switch Tester USER GUIDE

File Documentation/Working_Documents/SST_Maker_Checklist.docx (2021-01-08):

## Maker To Do

☐ Order Hardware Components

☐ Print 3D Printed Components

- 1 x Switch Tester Bottom
- 1 x Switch Tester Top
- 1 x Switch Tester Cover

☐ Assemble Simple Switch Tester

☐ Test Simple Switch Tester

☐ Clean and package Simple Switch Tester

☐ Print out Simple Switch Tester: Quick Guide

# Items for the User

☐ Tested, cleaned, and packaged Simple Switch Tester

☐ Simple Switch Tester: Quick Guide

© 2020 by Neil Squire. “Simple Switch Tester Maker Checklist” is licensed under the CC BY SA 4.0 License: http://creativecommons.org/licenses/by-sa/4.0 PAGE 1 OF 3 Design files available at https://www.makersmakingchange.com/project/simple-switch-tester/

V0.1 | DECEMBER 2020 Simple Switch Tester Maker Checklist

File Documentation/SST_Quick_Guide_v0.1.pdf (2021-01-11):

V0.1 | DECEMBER 2020

# Simple Switch Tester

## USER GUIDE

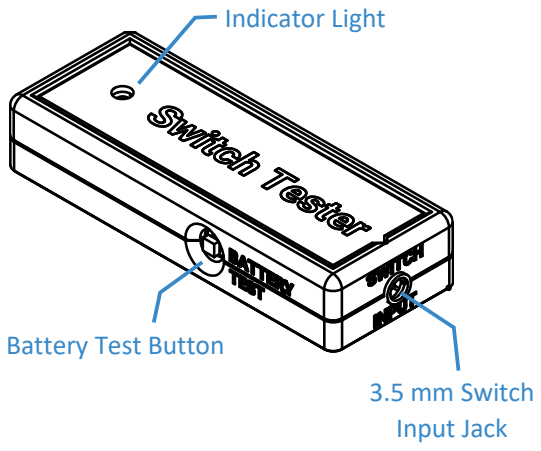
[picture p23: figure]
Indicator Light; Battery Test Button; 3.5 mm Switch Input Jack

© 2020 by Neil Squire. (https://neilsquire.ca/) This work is licensed under the CC BY SA 4.0 License: http://creativecommons.org/licenses/by-sa/4.0 Design files available at https://www.makersmakingchange.com/project/simple-switch-tester

### Introduction

The Simple Switch Tester enables a user to test the functionality of an assistive switch equipped with a 3.5 mm plug. When a switch is plugged into the 3.5 mm jack and activated, an indicator light will illuminate indicating a successfully operating switch.

### Features

### Specification

Size | 110 x 42 x 21 mm (w x d x h)
Input | 3.5 mm
Batteries | 2 X AAA
Disinfection | Ethyl Alcohol, Isopropyl Alcohol, Hydrogen Peroxide

### Usage – Check Tester

1. Press the “BATTERY TEST” button on the side of the enclosure.
2. If the batteries are working, the indicator light will turn on.

### Usage – Test Switch

1. Plug an assistive switch into the 3.5 mm input jack on the end of the enclosure.
2. The indicator light should NOT turn on. If it does, there may be something wrong with the switch.
3. Activate the assistive switch.
4. The indicator light should turn ON. If the light does not turn on, there may be something wrong with the switch.

### Cleaning

Wipe the exterior of the enclosure with a damp cloth.

V0.1 | DECEMBER 2020

# Simple Switch Tester

## USER GUIDE

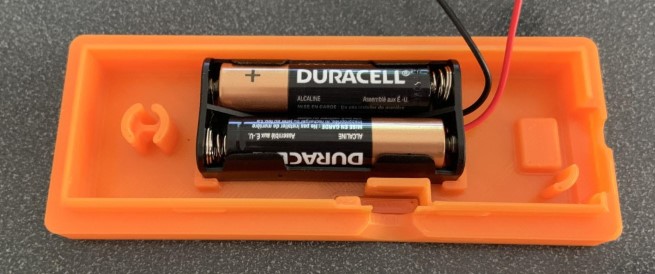
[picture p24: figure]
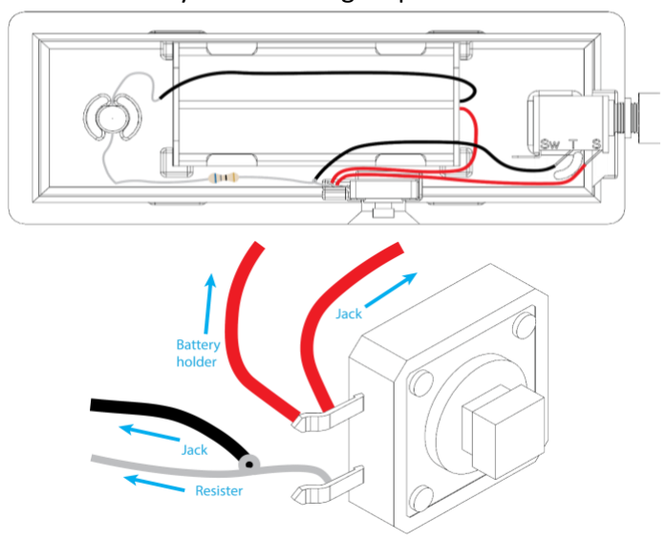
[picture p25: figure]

© 2020 by Neil Squire. (https://neilsquire.ca/) This work is licensed under the CC BY SA 4.0 License: http://creativecommons.org/licenses/by-sa/4.0 Design files available at https://www.makersmakingchange.com/project/simple-switch-tester

### Troubleshooting

Issue: Indicator light does not turn on when the “BATTERY TEST” button is pushed:
1. Check that the batteries are fresh and installed in the correct direction (indicated on the battery holder).
2. Check to make sure all the wires are connected correctly and in the right spots.

The LED stays on all the time:
1. Make sure the wires are not accidentally touching each other or soldered together incorrectly.

The LED turns on when the test button is pushed, but not when the assistive switch is activated:
1. Check to ensure the assistive switch is plugged into the jack correctly/all the way.
2. The assistive switch may not be assembled correctly/not working.

### Replacing Batteries

Replacing the Batteries
1. Loosen the 3.5 mm jack nut without removing it and pull apart the two halves of the enclosure, exposing the electronics inside.
2. Remove the old batteries and dispose of them appropriately (recycle or recharge).
3. Insert the two new AAA batteries. Ensure they are installed in the correct orientation.
4. Check the tester by pressing the “BATTERY TEST” button to see if the indicator light illuminates.
5. Re-assemble the enclosure. Snap the two halves back together and tighten the nut on the
3.5 mm jack.

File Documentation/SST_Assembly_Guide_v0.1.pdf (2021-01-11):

# Simple Switch Tester

# ASSEMBLY MANUAL

V1.0 | tiny.cc/MMCproj | PAGE 1 OF 3 | ORIGINAL DESIGN BY MAKERS MAKING CHANGE

### 01. Place a SMALL amount of superglue on the inner

ledges of the top of the enclosure.

### 03. Measure 7 cm from the end of the BLACK wire and

9 cm from the end of the RED wire and cut them.

### 02. Place the lithophane on the ledges, ensuring the

text is face-up, and wait 10 minutes for it to dry.

### 04. Strip all four wires ends by

1 cm and twist them.

05. Bend all the ends into hooks with pliers. | 06. Bend the ends of the LED leads and hook the shorter one (flat side, negative) to the anchored BLACK wire. Solder it in place.

### 07. Bend the resistor ends and hook one end to the

longer LED lead (positive). Solder it in place. | 08. Bend the other end of the resistor in a loop with pliers and hook the loose BLACK wire in it. Solder it in place.
0 | 1cm | 3cm

TURN

2cm

### 9 cm

### 7 cm

1cm

TWIST

FLIP

Flat side

# ASSEMBLY MANUAL

V1.0 | tiny.cc/MMCproj | PAGE 2 OF 3 | ORIGINAL DESIGN BY MAKERS MAKING CHANGE
09. Cut off two leads and the two nubs on the back of the switch, and bend the other two leads into an “L” shape. | 10. Hook the resistor on the bottom switch lead and solder it in place.
TOP LEAD 11.Hook the anchored RED wire and one end of the loose RED wire on the top switch lead and solder them in place. | 12. Hook the other end of the loose RED wire to the first jack lead and hook the end of the loose BLACK wire to the middle jack lead. Solder them in place.
45° 13. Bend the last jack lead horizontal and the other two 45°. | - + 14. Insert two AAA batteries.
15. The circuit should look like this. | 16. Press the switch to test if the device is working.

FLIP

BOTTOM LEAD

90°

# ASSEMBLY MANUAL

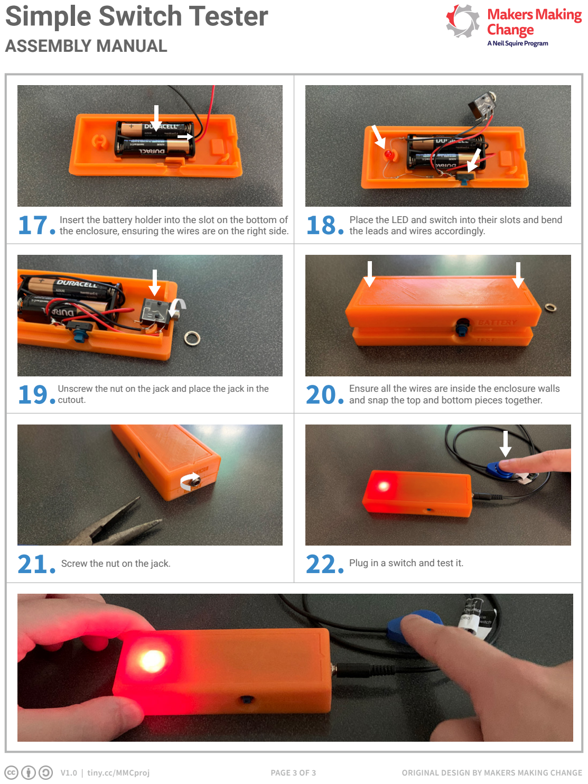
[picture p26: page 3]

V1.0 | tiny.cc/MMCproj | PAGE 3 OF 3 | ORIGINAL DESIGN BY MAKERS MAKING CHANGE
17.Insert the battery holder into the slot on the bottom of the enclosure, ensuring the wires are on the right side. | 18. Place the LED and switch into their slots and bend the leads and wires accordingly.
19.Unscrew the nut on the jack and place the jack in the cutout. | 20. Ensure all the wires are inside the enclosure walls and snap the top and bottom pieces together.
21. Screw the nut on the jack. | 22. Plug in a switch and test it.

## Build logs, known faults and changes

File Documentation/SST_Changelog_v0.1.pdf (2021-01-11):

V0.1 | JANUARY 2021

# Simple Switch Tester

# CHANGELOG

© 2021 by Neil Squire. (https://neilsquire.ca/) This work is licensed under the CC BY SA 4.0 License: http://creativecommons.org/licenses/by-sa/4.0
Design files available at https://www.makersmakingchange.com/project/simple-switch-tester/ | PAGE 1 OF 1

V0.1

- Initial release.

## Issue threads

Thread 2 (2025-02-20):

CAD Files are missing

jakemcivor, 2025-02-20:

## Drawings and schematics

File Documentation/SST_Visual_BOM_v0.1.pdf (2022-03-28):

# PART 0

### COMPONENT CHECKLIST

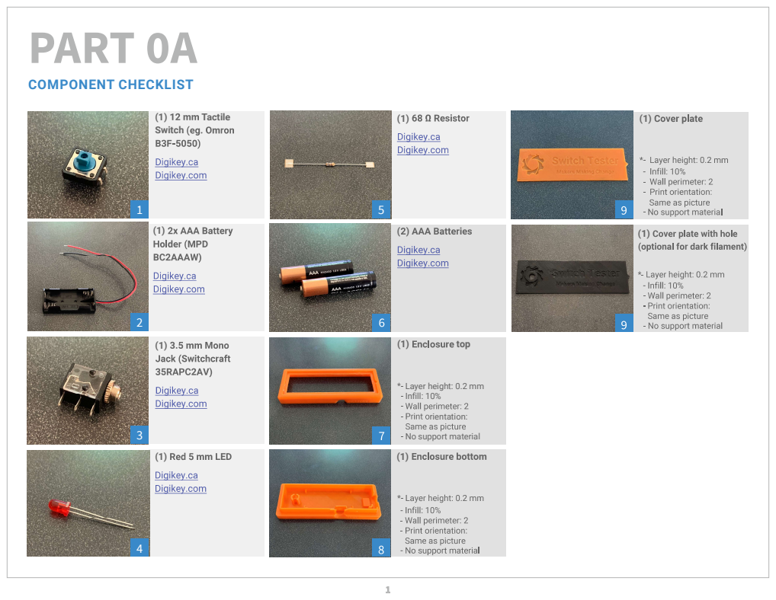
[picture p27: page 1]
(1) Tactile Switch; (1) top; rientation:

Layer height: 0.2 mm
Infill: 10%

No support material

# PART 0

### EQUIPMENT CHECKLIST

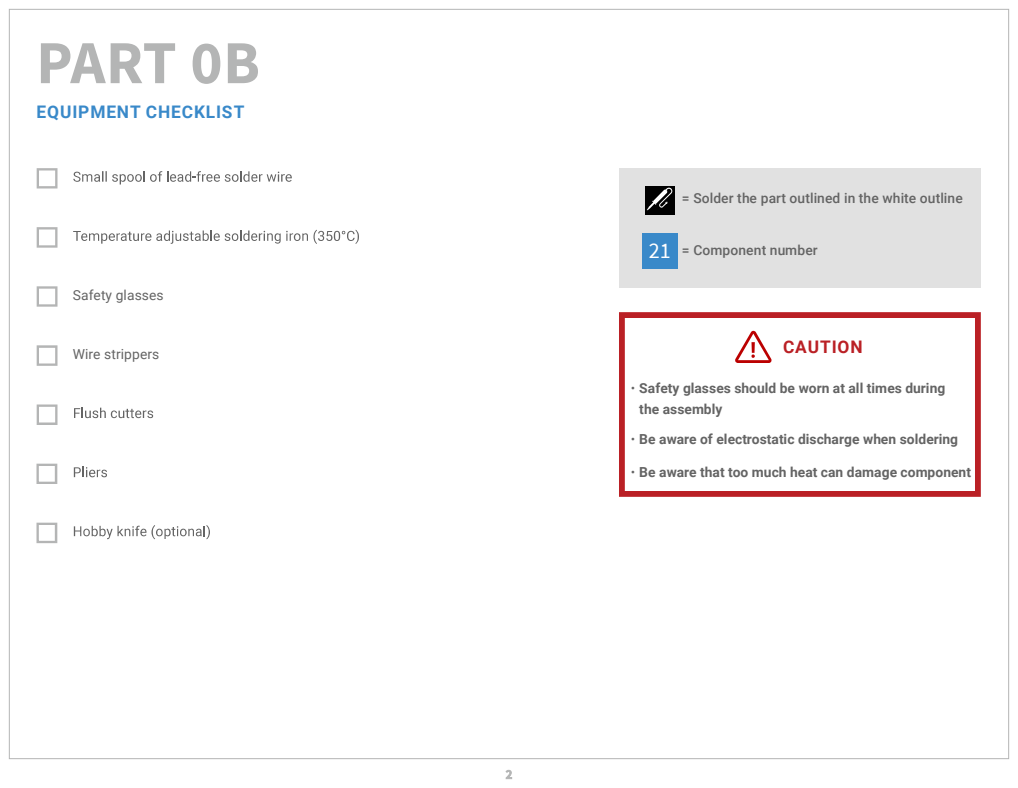
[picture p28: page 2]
Safety glasses; Wire strippers; 21 = Component number; CAUTION

= Solder the part outlined in the white outline

• Safety glasses should be worn at all times during
the assembly
• Be aware of electrostatic discharge when soldering

• Be aware that too much heat can damage component

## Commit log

2021-01-07 Update SST_Enclosure_Bottom.stl
    Add MAKERS MAKING CHANGE engrave to bottom
    [SST_Enclosure_Bottom.stl]
2021-01-07 Create SST.gif
    Add animated gif of battery test and switch test.
2021-01-11 Update README.md
    Remove 3D printing Guide link for now.
2021-01-12 Add Digikey Cart Link
    [SST_BOM_v0.1.xlsx]
2021-10-14 Updated Digikey Cart Link
    Updated Digikey Cart Link with alternative LED option.
2021-12-15 Added STL files for two-color cover plate print
    [SST_Dual_Cover_Plate.stl, SST_Dual_Letters.stl]
2022-03-28 Added visual BOM
2022-03-28 Add files via upload
    Add visual BOM
